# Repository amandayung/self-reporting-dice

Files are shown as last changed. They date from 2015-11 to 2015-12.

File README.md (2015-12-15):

# Self-Reporting Dice

This was a final project for the HCI class "Designing UX for Internet-Enabled Devices" (HCIN-720) at the Rochester Institute of Technology. We developed a pair of dice where one sends its roll results via the cloud, and the other physically rolls itself to match the paired die. We envision these dice can be used for playing tabletop games remotely with other players.

[**Project Video (hosted on YouTube)**](https://youtu.be/str3CotXbzo)

[**Project Writeup**](https://github.com/amandayung/self-reporting-dice/blob/master/final-project-writeup.pdf)

### Earlier Proposals

[**Updated Project Proposal**](https://github.com/amandayung/self-reporting-dice/blob/master/final-project-proposal-updated.pdf)

[**Project Proposal**](https://github.com/amandayung/self-reporting-dice/blob/master/final-project-proposal.pdf)

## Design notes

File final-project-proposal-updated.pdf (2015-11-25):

# Final Project Proposal: Self-Reporting Dice

Katherine Cummings
Rochester Institute of
Technology
Rochester, NY 14623, USA
rmc9454@rit.edu

Amanda Yung
Rochester Institute of
Technology
Rochester, NY 14623, USA
aky2875@rit.edu

Permission to make digital or hard copies of all or part of this work for personal or classroom use is granted without fee provided that copies are not made or distributed for profit or commercial advantage and that copies bear this notice and the full citation on the first page. Copyrights for components of this work owned by others than ACM must be honored. Abstracting with credit is permitted. To copy otherwise, or republish, to post on servers or to redistribute to lists, requires prior specific permission and/or a fee. Request permissions from permissions@acm.org.

### Abstract

We propose to create a self-reporting die that can be used to play tabletop games over the internet. This paper outlines the problem to be solved by our project and the steps we will take to implement our solution. Additionally, current research in the field that supports our proposed solution is outlined within.

### Author Keywords

Dice; Tabletop Gaming; Orientation Sensors.

### ACM Classification Keywords

H.5.m [HCI]: Miscellaneous

### Problem

Recently there has been a rise in popularity of tabletop gaming, ranging from board games to role-playing games. Typically, tabletop games must be played in a shared space, but this has not prevented players from attempting to play remotely with their friends. We would like to make tabletop gaming a more engaging and efficient experience when one or more of the game's players are playing together via an internet connection. In particular, we would like to improve the experience of dice rolling in tabletop role-playing games. Currently, this is most often solved with a webcam and random number generator. However, for the player who must rely on these methods to be a part of the game, their game experience is diluted: they miss out on the interactions that come with sitting in the same room with friends and playing together.

Players in this situation often try to improve their game experiences by rolling their own physical dice, but this only further complicates the situation. The die roller must self-report their roll results to their fellow players as opposed to having the random number generator post it for all to see. This adds one additional step to the process of play, which seems small, but given the number of rolls that can take place during one session of play, the time lost will add up swiftly. The self-report is also vulnerable to fabrication; in a critical moment, a player whose dice rolls cannot be seen may lie about their results, changing the outcome to suit their needs. Without the automated self-report to keep all players honest, there might be a degree of cheating that arises from some players.

### Literature Review

Virtual & Augmented Gaming
Several consumer software products attempt to address the problem of playing tabletop role-playing games remotely [1]. However, these only offer a digital environment to play in. Tabletop games are enjoyed in part due to their physical nature: the tactile feedback given in these games, such as a player moving game pieces or rolling dice, can enhance the game experience [2, 6].

Previous research has been conducted to determine ideal ways to augment physical games with digital environments. For example, Hinske et al.'s work involving the tabletop miniatures game Warhammer 40K used digital information collected from natural play to automate some of the more mundane game mechanics, such as determining line of sight for a unit [2]. They also developed augmented dice with RFID tags to automatically determine the roll result, but RFID dice have their limitations: one of the drawbacks is the necessity to use an external sensor, which limits the space a player can roll the dice [3].

Magerkurth et al. have also investigated how to augment the act of rolling dice with the Smart Dice Cup [6]. The Smart Dice Cup mimics the act of shaking dice in a cup and revealing the outcome, such as for the game Yahtzee. An accelerometer detects the shaking motion, which activates the random number generator. Additionally, LEDs on the Smart Dice Cup light up to indicate the roll result. However, the physicality of the dice is lost, as they have become digitized and replaced with a single cup.

Orientation Sensing
Orientation sensing technology can allow for a handheld object to report its positioning to a user. While limited research has been conducted about orientation sensing for dice in particular, a great deal of research has been done in regards to orientation sensing technology and its application for smartphone use. Most prominently in this area, smartphone orientation sensors are being explored as potential control mechanisms for the phone, allowing the user to perform tasks by shifting the position and angle of their phone. Specifically, its application as a form of authentication has been a popular subject with several proposed methods having been put forward [4, 5]. These studies have claimed a high degree of precision from the orientation sensor's readings: the sensors could detect unique subtleties in a user's hand and wrist motion, such that they were able to tell two users apart who performed the same gestures.

Concepts for tracking orientation sensor positioning via the internet have also been proposed. Uhchikoshi et al. have created a method of tracking a smartphone's location from data provided by a smartphone's orientation sensor and camera and transmitted via Wi-Fi, allowing users to reclaim a misplaced phone. Difficulties exist when executing this method in real-time however, due to the pronounced processing cost [7].

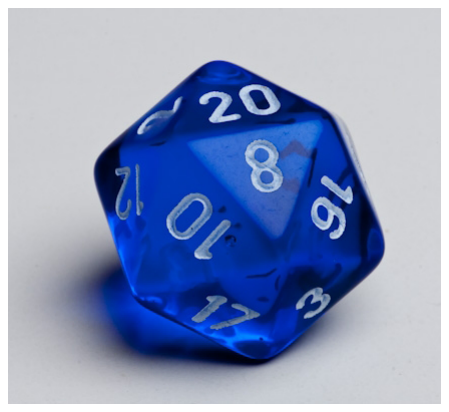
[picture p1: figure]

Figure 1: A standard D20.

### Proposal

We propose an internet-connected twenty-sided die, or D20 (see Figure 1), that will send its roll outcome via Wi-Fi. This information will be sent to a paired D20 that will be rolled to match the other D20’s outcome. The D20 was chosen due to its iconic status in role-playing games like Dungeons & Dragons: typically D20 rolls determine the outcome for major events in the game. For clarity, we will refer to the first D20 as the player D20, and the other as the DM D20, as a reference to the overseeing dungeon master (DM) who needs to be aware of player actions.

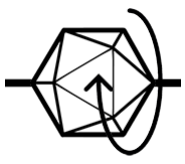
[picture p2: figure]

Figure 2: First axis of rotation.

The player D20 will contain an absolute orientation sensor, a Photon, and a battery. The orientation sensor will integrate data from an accelerometer, magnetometer, and gyroscope to determine the orientation of the die. The Photon will process the orientation sensor data to indicate what side the D20 landed on, and it will also send this data using the Particle Cloud. The battery will power the Photon in order for the player D20 to be wireless.

A node.js server will be used as an intermediary between the player D20 and the DM D20. When the server receives the final die roll result from the player D20, this information will be then sent to the DM D20 via serial port.

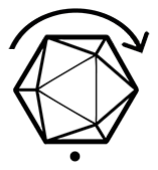
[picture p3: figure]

Figure 3: Second axis of rotation. Cross-section of axis is illustrated with dot.

The DM D20 will consist of a 3D-printed D20 moved around by two stepper motors. The stepper motors will serve as external forces to automatically re-position the D20 so that the rolled side is facing upwards, in order to indicate what the player D20 landed on. One stepper motor will rotate the

D20 around an axis through two opposing points of the die (see Figure 2). The D20 will appear like it is suspended in air, as we intend to use a clear material, such as acrylic, for the motor axle. The D20, stepper motor, and axle supporting the D20 will then be attached to a platform. The platform will have a stepper motor built into it that will be capable of rotating the entire platform. This gives the D20 a new axis of rotation (see Figure 3). With these two rotation axes, it will be possible to spin any side of the D20 to face upwards.

To indicate activity on the player D20 side, the DM D20 will randomly spin around and then eventually land on the player D20’s outcome. This action will help the user of the DM D20 know when to pay attention to display. Furthermore, it helps to mimic the typical characteristic of randomness inherent in all standard dice. The stepper motors will be controlled by a motor shield attached to an Arduino. The motors will be powered by a wall power adapter, due to the amount of power the two motors will require to run.

### Implementation

We intend to take the following steps in order to successfully implement our project. The steps for the player D20 and the DM D20 will be completed in parallel:

Player D20
1. Wire orientation sensor and battery to Photon.
2. Test and calibrate the orientation sensor.
3. Solder internal components for smallest form factor.
4. Design a D20 case that houses internal components.
5. Prototype D20 cases to check for proper size and durability.

6. 3D print the final D20 case and integrate internal components.
7. Collect data to determine what orientation information corresponds to which side of the D20.
8. Test sending this data to the node.js server.

DM D20
1. Wire stepper motors to Arduino.
2. Test the stepper motors.
3. Test commands sent to Arduino via serial port for controlling the stepper motor positions.
4. Build and test first axis of rotation rig that is directly connected to D20.
5. Build and test second axis of rotation platform that supports the first axis rig.
6. Test sending actual data from player D20 to DM D20 and displaying the correct output.

### REFERENCES

1. Charlie Hall. 2015. There’s more than one way to play
D&D with your friends online. (2015). http://www.polygon.com/2015/4/23/8482451/cheap-free-dungeons-and-dragons-online-tabletop-pen-and-paper. (http://www.polygon.com/2015/4/23/8482451/cheap-free-dungeons-and-dragons-online-tabletop-pen-and-paper)
2. Steve Hinske and Marc Langheinrich. 2009. W41K: Digitally Augmenting Traditional Game Environments.
In Proceedings of the 3rd International Conference on Tangible and Embedded Interaction (TEI ’09). ACM, New York, NY, USA, 99–106. DOI: http://dx.doi.org/10.1145/1517664.1517691
3. Steve Hinske, Marc Langheinrich, and Yves Alter. 2008. Building RFID-Based Augmented Dice with Perfect Recognition Rates. In Proceedings of the 2Nd International Conference on Fun and Games. Springer-Verlag, Berlin, Heidelberg, 59–64. DOI: http://dx.doi.org/10.1007/978-3-540-88322-7_6
4. Ankita Jain and Vivek Kanhangad. 2015. Exploring orientation and accelerometer sensor data for personal authentication in smartphones using touchscreen gestures. Pattern Recognition Letters (2015), –. DOI: http://dx.doi.org/10.1016/j.patrec.2015.07.004
5. Chien-Cheng Lin, Deron Liang, Chin-Chun Chang, and Ching-Han Yang. 2012. A New Non-Intrusive Authentication Method Based on the Orientation Sensor for Smartphone Users. In Software Security and Reliability (SERE), 2012 IEEE Sixth International Conference on. 245–252. DOI: http://dx.doi.org/10.1109/SERE.2012.37
6. Carsten Magerkurth, Timo Engelke, and Carsten Röcker. 2006. The Smart Dice Cup: A Radio Controlled Sentient Interaction Device. In Proceedings of the 5th International Conference on Entertainment Computing (ICEC’06). Springer-Verlag, Berlin, Heidelberg, 211–216. DOI:http://dx.doi.org/10.1007/11872320_25
7. Daisei Uhchikoshi, Takeshi Iwamoto, and Michito Matsumoto. 2014. Location Method for Smartphone Using Camera and Orientation Sensor. In Proceedings of the 2014 International Workshop on Web Intelligence and Smart Sensing (IWWISS ’14). ACM, New York, NY, USA, Article 21, 2 pages. DOI: http://dx.doi.org/10.1145/2637064.2637108

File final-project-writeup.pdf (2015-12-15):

# Final Project Writeup: Self-Reporting Dice

Katherine Cummings
Rochester Institute of
Technology
Rochester, NY 14623, USA
rmc9454@rit.edu

Amanda Yung
Rochester Institute of
Technology
Rochester, NY 14623, USA
aky2875@rit.edu

Permission to make digital or hard copies of all or part of this work for personal or classroom use is granted without fee provided that copies are not made or distributed for profit or commercial advantage and that copies bear this notice and the full citation on the first page. Copyrights for components of this work owned by others than ACM must be honored. Abstracting with credit is permitted. To copy otherwise, or republish, to post on servers or to redistribute to lists, requires prior specific permission and/or a fee. Request permissions from permissions@acm.org.

### Abstract

Playing tabletop games remotely with other players can lack the enjoyment of playing together in a shared space due to the virtualization of required game components, such
as dice. We propose and have developed working prototypes of a die that self-reports the face-value of its rolls and a linked partner die that automatically displays the communicated results. These dice would allow tabletop game players who are unable to play together locally to have a more engaging experience when playing over the internet. Additionally, we review current research in the field that supports our proposed solution.

### Author Keywords

Dice; Tabletop Gaming; Orientation Sensors.

### ACM Classification Keywords

H.5.m [HCI]: Miscellaneous

### Introduction

Recently there has been a rise in popularity of tabletop gaming, ranging from board games to role-playing games. Typically, tabletop games must be played in a shared space, but this has not prevented players from attempting to play remotely with their friends. Currently, this is most often solved with a webcam and random number generator. However, for the player who must rely on these methods to be a part of the game, their game experience is diluted: they miss out on the interactions that come with sitting in the same room with friends and playing together.

Players in this situation often try to improve their game experiences by rolling their own physical dice, but this only further complicates the situation. The die roller must self-report their roll results to their fellow players as opposed to having the random number generator post it for all to see. This adds one additional step to the process of play, which seems small, but given the number of rolls that can take place during one session of play, the time lost will add up swiftly. The self-report is also vulnerable to fabrication; in a critical moment, a player whose dice rolls cannot be seen may lie about their results, changing the outcome to suit their needs. Without the automated self-report to keep all players honest, there might be a degree of cheating that arises from some players.

We sought to make tabletop gaming a more engaging and efficient experience when one or more of the game’s players are playing together via an internet connection. In particular, we wanted to improve the experience of dice rolling in tabletop role-playing games. We created a pair of dice, called the self-reporting dice: a player can roll a physical die that sends roll results over the internet, and these results can then be received by a paired die to show the die roll to other players remotely. Our solution retains the tactile experience of dice rolling.

### Related Work

Virtual & Augmented Gaming
Several consumer software products attempt to address the problem of playing tabletop role-playing games remotely [1]. However, these only offer a digital environment to play in. Tabletop games are enjoyed in part due to their physical nature: the tactile feedback given in these games, such as a player moving game pieces or rolling dice, can enhance the game experience [2, 6].

Previous research has been conducted to determine ideal ways to augment physical games with digital environments. For example, Hinske et al.’s work involving the tabletop miniatures game Warhammer 40K used digital information collected from natural play to automate some of the more mundane game mechanics, such as determining line of sight for a unit [2]. They also developed augmented dice with RFID tags to automatically determine the roll result, but RFID dice have their limitations: one of the drawbacks is the necessity to use an external sensor, which limits the space a player can roll the dice [3].

Magerkurth et al. have also investigated how to augment the act of rolling dice with the Smart Dice Cup [6]. The Smart Dice Cup mimics the act of shaking dice in a cup and revealing the outcome, such as for the game Yahtzee. An accelerometer detects the shaking motion, which activates the random number generator. Additionally, LEDs on the Smart Dice Cup light up to indicate the roll result. However, the physicality of the dice is lost, as they have become digitized and replaced with a single cup.

Orientation Sensing
Orientation sensing technology can allow for a handheld object to report its positioning to a user. While limited research has been conducted about orientation sensing for dice in particular, a great deal of research has been done in regards to orientation sensing technology and its application for smartphone use. Most prominently in this area, smartphone orientation sensors are being explored as potential control mechanisms for the phone, allowing the user to perform tasks by shifting the position and angle of their phone. Specifically, its application as a form of authentication has been a popular subject with several proposed methods having been put forward [4, 5]. These studies have claimed a high degree of precision from the orientation sensor’s readings: the sensors could detect unique subtleties in a user’s hand and wrist motion, such that they were able to tell two users apart who performed the same gestures.

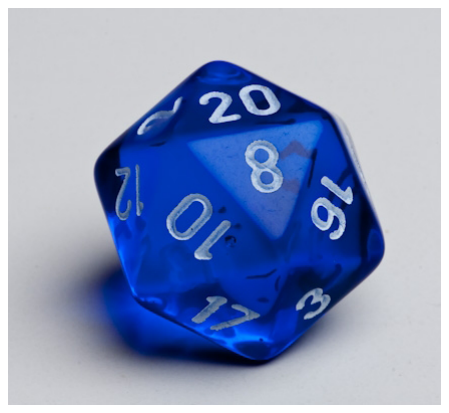
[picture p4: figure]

Figure 1: A standard D20.

Concepts for tracking orientation sensor positioning via the internet have also been proposed. Uhchikoshi et al. have created a method of tracking a smartphone’ s location from data provided by a smartphone’s orientation sensor and camera and transmitted via wi-fi, allowing users to reclaim a misplaced phone. Difficulties exist when executing this method in real-time however, due to the pronounced processing cost [7].


Figure 2: First axis of rotation.

### Proposal

At the start of this project, we proposed an internet-connected twenty-sided die, or D20 (see Figure 1), that would send its roll outcome via wi-fi. This information would be sent to a paired D20 that would be rolled to match the other D20’s outcome. The D20 was chosen due to its iconic status in role-playing games like Dungeons & Dragons: typically D20 rolls determine the outcome for major events in the game. For clarity, we will refer to the first D20 as the wi-fi die, and the other as the display die.


Figure 3: Second axis of rotation. Cross-section of axis is illustrated with dot.

The wi-fi die would contain an absolute orientation sensor, a Photon, and a battery. The orientation sensor would integrate data from an accelerometer, magnetometer, and gyroscope to determine the orientation of the die. The Photon would process the orientation sensor data to indicate what side the D20 landed on, and it would also send this data using the Particle Cloud. The battery would power the Photon in order for the wi-fi die to be wireless.

A node.js server would be used as an intermediary between the wi-fi die and the display die. When the server receives the final die roll result from the wi-fi die, this information would be then sent to the display die via serial port.

The display die would consist of a 3D-printed D20 moved around by two stepper motors. The stepper motors would serve as external forces to automatically re-position the D20 so that the rolled side is facing upwards, in order to indicate what the wi-fi die landed on. One stepper motor would rotate the D20 around an axis through two opposing points of the die (see Figure 2). The D20 would appear like it is suspended in air, as we intend to use a clear material, such as acrylic, for the motor axle. The D20, stepper motor, and axle supporting the D20 would then be attached to a platform. The platform would have a stepper motor built into it that would be capable of rotating the entire platform. This gives the D20 a new axis of rotation (see Figure 3). With these two rotation axes, it would be possible to spin any side of the D20 to face upwards.

To indicate activity on the wi-fi die side, the display die would randomly spin around and then eventually land on the wi-fi die’s outcome. This action would help the user of the display die know when to pay attention to the display. Furthermore, it helps to mimic the typical characteristic of randomness inherent in all standard dice. The stepper motors would be controlled by a motor shield attached to an Arduino. The motors would be powered by a wall power adapter, due to the amount of power the two motors would require to run.

We planned to take the following steps in order to successfully implement our project. The steps for the wi-fi die and the display die would be completed in parallel:

Wi-Fi Die
1. Wire orientation sensor and battery to Photon.
2. Test and calibrate the orientation sensor.
3. Solder internal components for smallest form factor.
4. Design a D20 case that houses internal components.
5. Prototype D20 cases to check for proper size and durability.
6. 3D print the final D20 case and integrate internal components.
7. Collect data to determine what orientation information corresponds to which side of the D20.
8. Test sending this data to the node.js server.

Display Die
1. Wire stepper motors to Arduino.
2. Test the stepper motors.
3. Test commands sent to Arduino via serial port for controlling the stepper motor positions.
4. Build and test first axis of rotation rig that is directly connected to D20.
5. Build and test second axis of rotation platform that supports the first axis rig.
6. Test sending actual data from wi-fi die to display die and displaying the correct output.

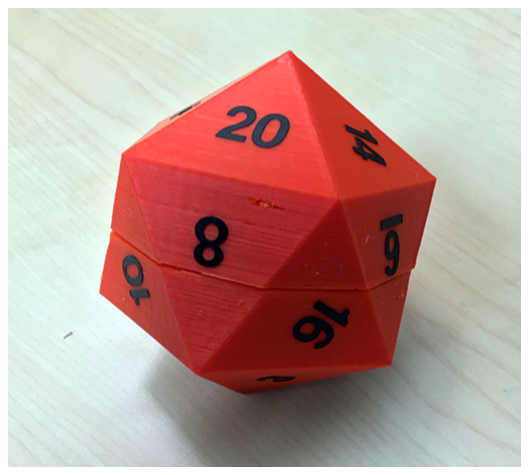
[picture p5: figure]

Figure 4: The wi-fi die.

### Implementation

The dice we created match with what we initially proposed to develop.

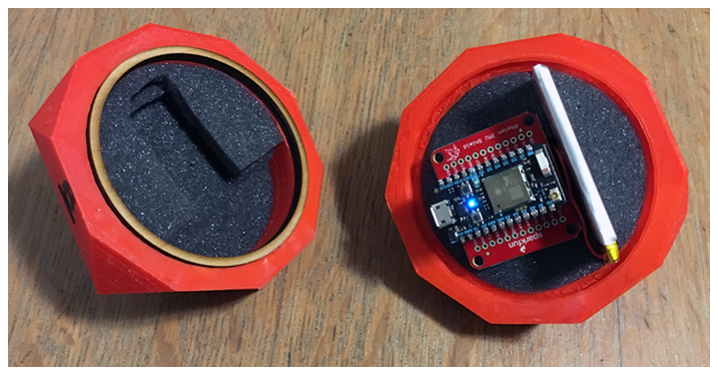
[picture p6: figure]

Figure 5: The contents of the wi-fi die.

Wi-Fi Die
The circuit inside the wi-fi die consists of a Photon, a Spark-Fun IMU shield, a SparkFun Photon battery shield, and
a 3.7V battery. Since all of the circuit pieces already had headers soldered to them, no additional soldering was necessary.

The die container is composed of 3D printed PLA filament (see Figure 4). It is approximately 11 cm in diameter in order to house all the circuit components. We filled the remaining space inside of the container with foam to provide padding for the circuit when the die is rolled. Since the battery must be recharged, the die can be re-opened for easy access to charge the battery via the Photon (see Figure 5). When the die is closed, a wooden ring acts as a lip to secure the two halves of the die together.

The firmware on the Photon sends relevant sensor information to the Particle cloud. Particularly, it sends 3-axis gyroscope data for angular velocity measures as well as 3-axis absolute orientation data, calculated from the 3-axis accelerometer and 3-axis magnetometer values. Readings are sent every second to a node.js server.

Node.js Server
The node.js server handles receiving the orientation readings from the wi-fi die via the Particle cloud and translates these values to the corresponding die side that was rolled. To determine the mapping between orientation data and die sides, we collected approximately 50 orientation data points for each of the 20 sides of the wi-fi die once the circuit was placed inside the container. Ranges for each side’s pitch, roll, and heading values were determined from these measurements. We use these minimum and maximum values as thresholds for categorizing a measure sent by the wi-fi die. The average of 3 readings is calculated to determine if a side has been rolled. Any averages which do not fall into one of the 20 sets of data ranges are not categorized as a side.

To ensure orientation readings are only used to determine a side when the die is stationary, we also collect angular velocity data from the wi-fi die. We calculated the standard deviation of approximately 50 gyroscope readings when the wi-fi die was at rest. We then used this value as a threshold to differentiate between when the die could be considered rolling and when it most likely was finished rolling.

Once a side has been determined, this side value is then sent to the display die via a serial port connection. The server also sends a flag for when the die begins to move, based on the gyroscope readings.

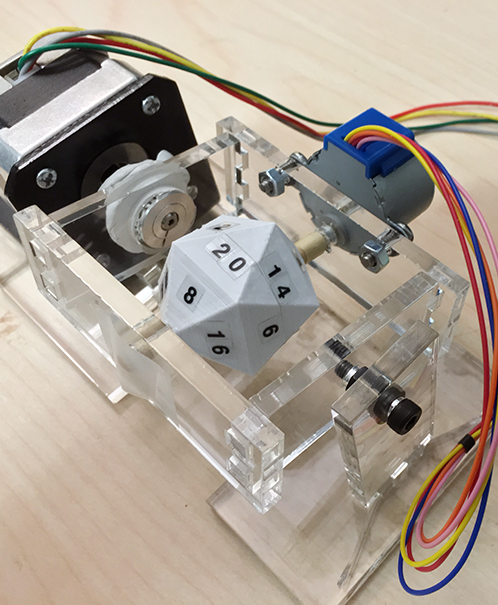
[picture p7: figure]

Figure 6: Side view of the display die.

Display Die
The display die is also made from 3D printed PLA filament and is approximately 3 cm in diameter. It is surrounded by a laser cut acrylic support system for the two stepper motors that enable the die to be rotated (see Figure 7). We used a clear material in order to increase visibility of the die. The die spins around a wooden dowel. A 12V 32-step unipolar stepper motor with a 1/16 reduction gear set spins

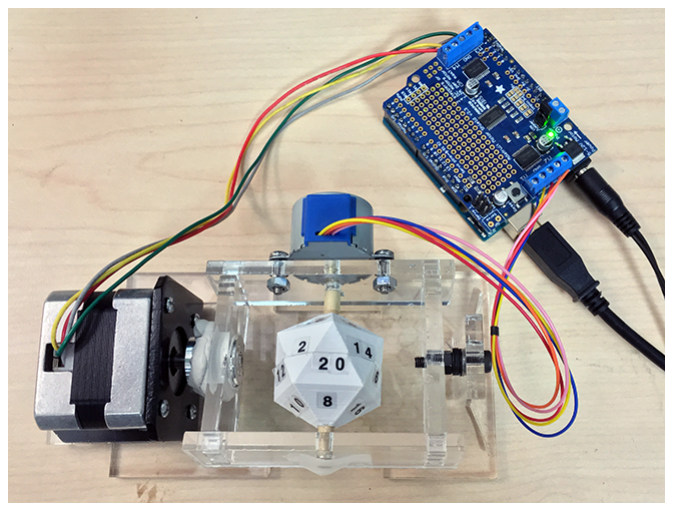
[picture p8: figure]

Figure 7: The display die. Here it indicates 20 has been rolled.

the wooden dowel for the display die’s first axis of rotation (see Figure 2). This motor is attached to the acrylic support system.

A 12V bipolar 200-step stepper motor then rotates the rectangular acrylic support system to create the die’s second axis of rotation (see Figure 3). To achieve this, the support system rotates around both the motor’s drive shaft and a bolt held up by an acrylic post (see Figure 6). Additional bolts and nuts secure the motors to the acrylic.

To hold up the center support system when the motors are not on, a small acrylic stand can be placed under it. This ensures that the zero state of the second motor is consistent.

An Arduino Uno with an Adafruit motor shield (V2) controls the two motors. The motors are powered by a 12V power adapter.

The side facing up (parallel to the floor, like a standard die) on the display die indicates the rolled side for the wi-fi die. The absolute position of each side for this configuration, in units of steps for the two motors, is hard-coded into the Arduino’s firmware. When a side value is sent, the motors then spin the die to show that side

Additionally, when the wi-fi die first begins to move, the display die’s first axis will rotate back and forth to mimic a rolling motion. It will continue to rotate until a side value has been received. This transparently indicates to the display die user that the person controlling the wi-fi die is currently rolling it.

### Conclusions

Creating a pair of dice that are aware of their respective orientations and are able to communicate with each other proved to be a feasible, if sensitive, endeavor. The wi-fi die successfully rolls and transmits accurate data on its final positioning without either the Photon or the 3D printed case becoming damaged from use, while the display die receives and re-orients itself correctly in response to the wi-fi die’s data.

With the dice being operationally successful we feel they offer some distinct advantages over the use of random number generators in online tabletop play. The primary benefit is that using these dice requires no special knowledge or training beyond that of regular set of dice. The wi-fi die functions exactly the same as one would use a standard 20 sided die; merely roll the die and read the number on the side facing up. While the display die has a more complex support arrangement around it, understanding its output is no different that the wi-fi die’s. Additionally in the case of the wi-fi die, it functions as a "magic object" as, apart from its larger than normal size, the die’s orientation sensing and wi-fi functionality remain wholly hidden from a user.

There were some disadvantages to the dice’s current design however, with the first being the large size of the wi-fi die. This proved to be unavoidable given the materials and technologies we had available to work with as the die needed to fit a Photon, a Photon IMU shield, a battery, and foam for protection within itself. With access to other, smaller versions of these same technologies it should be possible to construct a wi-fi die that is more approximate in size to its non-electronic counterparts.

Related to this point is an issue with the layout of the wi-fi die’s insides. The hollow space within the die requires some form of shock absorption lest the electronics it contains suffer damage when rolling the die. We settled on several layers of foam padding to meet this need. While this kept our electronics secure, it did mean that after long periods of use or any particularly forceful throws, the Photon shifts its placement inside the die, leading to skewed results from the IMU shield about its orientation and requiring minor manual readjustment.

The internal electronics together with the minor imperfections in the 3D printed exterior pose an additional issue to the wi-fi die: they ensure that the die is not balanced and therefore is not truly random in its results. While most common dice have minor imperfections that lead to the same sort of problem, the presence of electronics increase the effect to a much more pronounced degree. We postulated that this could be corrected for with a cleaner 3D print and a careful application of internal counterweights, but doing so was outside the scope of our intentions for this project.

The display die as well could be further improved. As it currently stands, the display die requires a bulky rig of motors around it to make it rotate. Our original intentions for the display die were different however; previously the die was to be free-moving, similar to the wi-fi die. We soon discovered that to carry through with this goal would require crafting complex gearwork inside the die, which, even if we were able to construct such a mechanism, would result in a final die much larger and far heavier than the wi-fi die, rendering it impractical to use.

With these successes and limitations in mind, we believe our project illustrates the potential value toward applying the ubiquitous technology principles to the field of tabletop gaming. Integrating technology into the pieces and tools of these games should make play more engaging and more streamlined of an experience for players.

### REFERENCES

1. Charlie Hall. 2015. There’s more than one way to play
D&D with your friends online. (2015). http://www.polygon.com/2015/4/23/8482451/cheap-free-dungeons-and-dragons-online-tabletop-pen-and-paper. (http://www.polygon.com/2015/4/23/8482451/cheap-free-dungeons-and-dragons-online-tabletop-pen-and-paper)
2. Steve Hinske and Marc Langheinrich. 2009. W41K: Digitally Augmenting Traditional Game Environments.
In Proceedings of the 3rd International Conference on Tangible and Embedded Interaction (TEI ’09). ACM, New York, NY, USA, 99–106. DOI: http://dx.doi.org/10.1145/1517664.1517691
3. Steve Hinske, Marc Langheinrich, and Yves Alter. 2008. Building RFID-Based Augmented Dice with Perfect Recognition Rates. In Proceedings of the 2Nd International Conference on Fun and Games.

Springer-Verlag, Berlin, Heidelberg, 59–64. DOI: http://dx.doi.org/10.1007/978-3-540-88322-7_6

4. Ankita Jain and Vivek Kanhangad. 2015. Exploring orientation and accelerometer sensor data for personal authentication in smartphones using touchscreen gestures. Pattern Recognition Letters (2015), –. DOI: http://dx.doi.org/10.1016/j.patrec.2015.07.004
5. Chien-Cheng Lin, Deron Liang, Chin-Chun Chang, and Ching-Han Yang. 2012. A New Non-Intrusive Authentication Method Based on the Orientation Sensor for Smartphone Users. In Software Security and Reliability (SERE), 2012 IEEE Sixth International Conference on. 245–252. DOI: http://dx.doi.org/10.1109/SERE.2012.37
6. Carsten Magerkurth, Timo Engelke, and Carsten Röcker. 2006. The Smart Dice Cup: A Radio Controlled Sentient Interaction Device. In Proceedings of the 5th International Conference on Entertainment Computing (ICEC’06). Springer-Verlag, Berlin, Heidelberg, 211–216. DOI:http://dx.doi.org/10.1007/11872320_25
7. Daisei Uhchikoshi, Takeshi Iwamoto, and Michito Matsumoto. 2014. Location Method for Smartphone Using Camera and Orientation Sensor. In Proceedings of the 2014 International Workshop on Web Intelligence and Smart Sensing (IWWISS ’14). ACM, New York, NY, USA, Article 21, 2 pages. DOI: http://dx.doi.org/10.1145/2637064.2637108

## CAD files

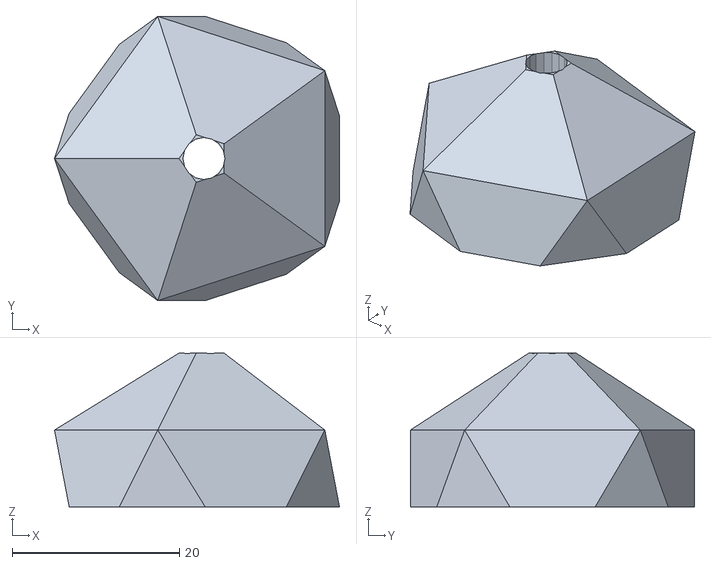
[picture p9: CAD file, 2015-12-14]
models/spinning_d20.stl
34.1 x 34.0 x 18.4

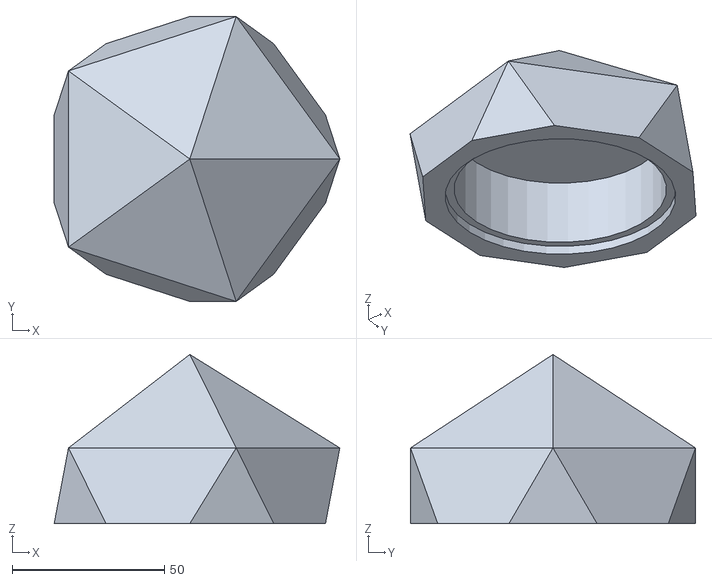
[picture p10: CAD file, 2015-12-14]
models/d20-bottom.stl
93.8 x 93.6 x 55.5

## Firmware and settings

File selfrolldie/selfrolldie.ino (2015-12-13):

// Requires the Adafruit_Motorshield v2 library 
//   https://github.com/adafruit/Adafruit_Motor_Shield_V2_Library
// And AccelStepper with AFMotor support 
//   https://github.com/adafruit/AccelStepper

// Code is based the Adafruit Motorshield tutorial included with the
// Adafruit libraries above

#include <AccelStepper.h>
#include <Wire.h>
#include <Adafruit_MotorShield.h>
#include "utility/Adafruit_PWMServoDriver.h"


// SerialEvent tutorial for getting data from serial port:
// http://www.arduino.cc/en/Tutorial/SerialEvent
//adding variables for storing string info
String inputString = "";         // a string to hold incoming data
boolean stringComplete = false;  // whether the string is complete

//add motorshield
Adafruit_MotorShield AFMS = Adafruit_MotorShield(); 

//add the two steppers (one with 32 steps and one with 200)
Adafruit_StepperMotor *myStepper1 = AFMS.getStepper(32, 1);
Adafruit_StepperMotor *myStepper2 = AFMS.getStepper(200, 2);

// you can change these to DOUBLE or INTERLEAVE or MICROSTEP!
// wrappers for the first motor!
void forwardstep1() {  
  myStepper1->onestep(FORWARD, SINGLE);
}
void backwardstep1() {  
  myStepper1->onestep(BACKWARD, SINGLE);
}
// wrappers for the second motor!
void forwardstep2() {  
  myStepper2->onestep(FORWARD, INTERLEAVE);
}
void backwardstep2() {  
  myStepper2->onestep(BACKWARD, INTERLEAVE);
}

// Now we'll wrap the 2 steppers in an AccelStepper object
AccelStepper stepper1(forwardstep1, backwardstep1);
AccelStepper stepper2(forwardstep2, backwardstep2);

//flag for whether to continually roll D20 or not
boolean isRolling = false;
long rollDuration = 500; //about 1 rotation


void setup() {
  //open connection to serial port
  Serial.begin(9600);

  // reserve 200 bytes for the inputString:
  inputString.reserve(200);

  AFMS.begin(); // Start the motor shield
   
  stepper1.setMaxSpeed(513.0);
  stepper1.setAcceleration(200.0);
  stepper1.moveTo(0);
    
  stepper2.setMaxSpeed(200.0);
  stepper2.setAcceleration(100.0);
  stepper2.moveTo(-10); //this is needed so that the motor actually holds itself up at the start
}

void loop() {
  serialEvent(); //get the serial message

  //now check to see what number was sent by the server
  if (stringComplete) {

    //if 0, then move die to starting position
    if (inputString.toInt() == 0) {
      resetD20();
      isRolling = false;
    }

    //if 21, then the die is currently "rolling"
    else if (inputString.toInt() == 21) {
      isRolling = true;
    }

    //otherwise, the die has settled on a side
    else {
      setD20();
      isRolling = false;
    }

    //clear the string
    inputString = "";
    stringComplete = false;
  }

  //check if the wifi die is currently still rolling;
  //if it is, then make sure the self-rolling die still moving
  if (isRolling) {
    rollD20();
  }

  //keep motors moving
  stepper1.run();
  stepper2.run();
}

void setD20() {
  //get side value from input string
  int side = inputString.toInt();
  long stepper1Location = 0;
  long stepper2Location = 0;

  //now move to the correct side
  switch(side) {
    case 1:
      stepper1Location = 255;
      stepper2Location = -7;
      break;
    case 2:
      stepper1Location = 51;
      stepper2Location = -7;
      break;
    case 3:
      stepper1Location = -204;
      stepper2Location = 51;
      break; 
    case 4:
      stepper1Location = -51;
      stepper2Location = -51;
      break;
    case 5:
      stepper1Location = 153;
      stepper2Location = -51;
      break;
    case 6:
      stepper1Location = -102;
      stepper2Location = 4;
      break;
    case 7:
      stepper1Location = 204;
      stepper2Location = 4;
      break;
    case 8:
      stepper1Location = 0;
      stepper2Location = 51;
      break;
    case 9:
      stepper1Location = -153;
      stepper2Location = -7;
      break;
    case 10:
      stepper1Location = 102;
      stepper2Location = 51;
      break;
    case 11:
      stepper1Location = -153;
      stepper2Location = -51;
      break;
    case 12:
      stepper1Location = 102;
      stepper2Location = 4;
      break;
    case 13:
      stepper1Location = 255;
      stepper2Location = -51;
      break;
    case 14:
      stepper1Location = -51;
      stepper2Location = -7;
      break;
    case 15:
      stepper1Location = 153;
      stepper2Location = -7;
      break;
    case 16:
      stepper1Location = -102;
      stepper2Location = 51;
      break;
    case 17:
      stepper1Location = 204;
      stepper2Location = 51;
      break;
    case 18:
      stepper1Location = 51;
      stepper2Location = -51;
      break;
    case 19:
      stepper1Location = -204;
      stepper2Location = 4;
      break;
    case 20:
      stepper1Location = 0;
      stepper2Location = 4;
      break;
    default:
      //go to resting state
      stepper1Location = 0;
      stepper2Location = 0;
      
    break;
  }

  stepper1.moveTo(stepper1Location);
  stepper2.moveTo(stepper2Location);
}

//set die to its starting position
void resetD20() {
  stepper1.moveTo(0);
  stepper2.moveTo(0);
}

//continually roll D20 until a side is settled on by the wifi die
void rollD20() {
  if (stepper1.distanceToGo() == 0) {
    rollDuration = -rollDuration;
    stepper1.moveTo(rollDuration);
  }
  stepper2.moveTo(0);
}

/*
  SerialEvent occurs whenever a new data comes in the
 hardware serial RX.  This routine is run between each
 time loop() runs, so using delay inside loop can delay
 response.  Multiple bytes of data may be available.
 */
void serialEvent() {
  while (Serial.available()) {
    // get the new byte:
    char inChar = (char)Serial.read();
    // add it to the inputString:
    inputString += inChar;
    // if the incoming character is a newline, set a flag
    // so the main loop can do something about it:
    if (inChar == '\n') {
      stringComplete = true;
    }
  }
}

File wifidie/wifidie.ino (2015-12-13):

/*****************************************************************
LSM9DS1_Basic_I2C.ino
SFE_LSM9DS1 Library Simple Example Code - I2C Interface
Jim Lindblom @ SparkFun Electronics
Original Creation Date: April 30, 2015
https://github.com/sparkfun/SparkFun_LSM9DS1_Particle_Library

The LSM9DS1 is a versatile 9DOF sensor. It has a built-in
accelerometer, gyroscope, and magnetometer. Very cool! Plus it
functions over either SPI or I2C.

This Photon sketch is a demo of the simple side of the
SFE_LSM9DS1 library. It'll demo the following:
* How to create a LSM9DS1 object, using a constructor (global
  variables section).
* How to use the begin() function of the LSM9DS1 class.
* How to read the gyroscope, accelerometer, and magnetometer
  using the readGryo(), readAccel(), readMag() functions and 
  the gx, gy, gz, ax, ay, az, mx, my, and mz variables.
* How to calculate actual acceleration, rotation speed, 
  magnetic field strength using the calcAccel(), calcGyro() 
  and calcMag() functions.
* How to use the data from the LSM9DS1 to calculate 
  orientation and heading.

Hardware setup: This library supports communicating with the
LSM9DS1 over either I2C or SPI. This example demonstrates how
to use I2C. 

If you have the Photon IMU shield, no extra wiring is required.
If you're using a breakout, the pin-out is as follows:
    LSM9DS1 --------- Photon
     SCL -------------- D1 (SCL)
     SDA -------------- D0 (SDA)
     VDD ------------- 3.3V
     GND ------------- GND
(CSG, CSXM, SDOG, and SDOXM should all be pulled high. 
Jumpers on the breakout board will do this for you.)

Development environment specifics:
    IDE: Particle Build
    Hardware Platform: Particle Photon
                       SparkFun Photon IMU Shield

This code is released under the MIT license.

Distributed as-is; no warranty is given.

Amanda's note: Code has been modified for sending gyroscope and orientation
values via the photon cloud
*****************************************************************/
#include "SparkFunLSM9DS1/SparkFunLSM9DS1.h"
#include "math.h"
#include "SparkJson/SparkJson.h" //for sending data in JSON format


//////////////////////////
// LSM9DS1 Library Init //
//////////////////////////
// Use the LSM9DS1 class to create an object. [imu] can be
// named anything, we'll refer to that throught the sketch.
LSM9DS1 imu;

///////////////////////
// Example I2C Setup //
///////////////////////
// SDO_XM and SDO_G are both pulled high, so our addresses are:
#define LSM9DS1_M   0x1E // Would be 0x1C if SDO_M is LOW
#define LSM9DS1_AG  0x6B // Would be 0x6A if SDO_AG is LOW

////////////////////////////
// Sketch Output Settings //
////////////////////////////
#define PRINT_CALCULATED
//#define PRINT_RAW
#define PRINT_SPEED 250 // 250 ms between prints

// Earth's magnetic field varies by location. Add or subtract 
// a declination to get a more accurate heading. Calculate 
// your's here:
// http://www.ngdc.noaa.gov/geomag-web/#declination
#define DECLINATION 11.45 // Declination (degrees) in Rochester, NY.

unsigned long startTime = 0;
unsigned long intervalCheck = 1000; //how often to send data to Photon cloud (1 sec is the minimum allowed)

void setup() 
{

  Serial.begin(115200);

  // Before initializing the IMU, there are a few settings
  // we may need to adjust. Use the settings struct to set
  // the device's communication mode and addresses:
  imu.settings.device.commInterface = IMU_MODE_I2C;
  imu.settings.device.mAddress = LSM9DS1_M;
  imu.settings.device.agAddress = LSM9DS1_AG;
  // The above lines will only take effect AFTER calling
  // imu.begin(), which verifies communication with the IMU
  // and turns it on.
  if (!imu.begin())
  {
    Serial.println("Failed to communicate with LSM9DS1.");
    Serial.println("Double-check wiring.");
    Serial.println("Default settings in this sketch will " \
                  "work for an out of the box LSM9DS1 " \
                  "Breakout, but may need to be modified " \
                  "if the board jumpers are.");
    while (1)
      ;
  }
  
    //initial start time
    startTime = millis();
}

void loop() {
    
     unsigned long currentTime = millis();
    
    //using an if statement so that it can be open for receiving commands
    if (currentTime - startTime > intervalCheck) {
        
        //update data
        imu.readGyro();
        imu.readAccel();
        imu.readMag();
        getAttitudeAndGyro(imu.ax, imu.ay, imu.az, -imu.my, -imu.mx, imu.mz, imu.gx, imu.gy, imu.gz);

         //reset start time
        startTime = millis();
    }
    
    
  //printGyro();  // Print "G: gx, gy, gz"
  //printAccel(); // Print "A: ax, ay, az"
  //printMag();   // Print "M: mx, my, mz"

  // Print the heading and orientation for fun!
  // Call print attitude. The LSM9DS1's magnetometer x and y
  // axes are opposite to the accelerometer, so my and mx areor
  // substituted for each other.
  //printAttitude(imu.ax, imu.ay, imu.az, -imu.my, -imu.mx, imu.mz);
  //Serial.println();

  //delay(PRINT_SPEED);
}


void printGyro()
{
  // To read from the gyroscope, you must first call the
  // readGyro() function. When this exits, it'll update the
  // gx, gy, and gz variables with the most current data.
  imu.readGyro();

  // Now we can use the gx, gy, and gz variables as we please.
  // Either print them as raw ADC values, or calculated in DPS.
  Serial.print("G: ");
#ifdef PRINT_CALCULATED
  // If you want to print calculated values, you can use the
  // calcGyro helper function to convert a raw ADC value to
  // DPS. Give the function the value that you want to convert.
  Serial.print(imu.calcGyro(imu.gx), 2);
  Serial.print(", ");
  Serial.print(imu.calcGyro(imu.gy), 2);
  Serial.print(", ");
  Serial.print(imu.calcGyro(imu.gz), 2);
  Serial.println(" deg/s");
#elif defined PRINT_RAW
  Serial.print(imu.gx);
  Serial.print(", ");
  Serial.print(imu.gy);
  Serial.print(", ");
  Serial.println(imu.gz);
#endif
}

void printAccel()
{
  // To read from the accelerometer, you must first call the
  // readAccel() function. When this exits, it'll update the
  // ax, ay, and az variables with the most current data.
  imu.readAccel();

  // Now we can use the ax, ay, and az variables as we please.
  // Either print them as raw ADC values, or calculated in g's.
  Serial.print("A: ");
#ifdef PRINT_CALCULATED
  // If you want to print calculated values, you can use the
  // calcAccel helper function to convert a raw ADC value to
  // g's. Give the function the value that you want to convert.
  Serial.print(imu.calcAccel(imu.ax), 2);
  Serial.print(", ");
  Serial.print(imu.calcAccel(imu.ay), 2);
  Serial.print(", ");
  Serial.print(imu.calcAccel(imu.az), 2);
  Serial.println(" g");
#elif defined PRINT_RAW 
  Serial.print(imu.ax);
  Serial.print(", ");
  Serial.print(imu.ay);
  Serial.print(", ");
  Serial.println(imu.az);
#endif

}
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

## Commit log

2015-12-13 added firmware for self-rolling die (arduino)
2015-12-13 Added wifi die firmware code (photon) and updated js code
2015-12-14 stl/ai models
    stl and ai files used in printing/cutting the dice/case
    [d20-bottom.stl, spinning_d20.stl]
2015-12-15 re-organizing files
    [d20-bottom.stl, spinning_d20.stl]
